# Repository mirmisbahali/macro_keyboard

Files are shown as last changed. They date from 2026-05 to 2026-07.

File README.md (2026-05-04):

# STM32 Macro Keyboard

A custom 6-key macro keyboard built from scratch custom written bare-metal STM32 firmware, hand-drawn schematics, and a PCB designed in KiCAD. No Arduino. No HAL. Just registers, datasheets, and stubbornness.

> **Status:** Hardware design in progress

---

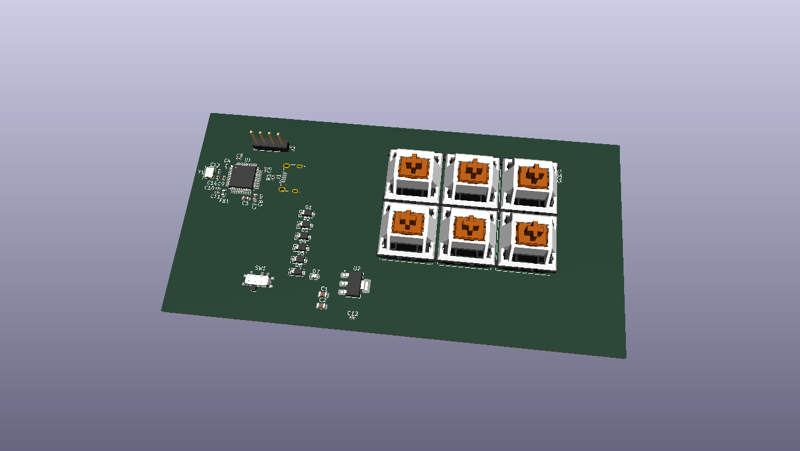
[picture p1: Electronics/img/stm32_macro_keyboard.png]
PCB


*PCB layout and routing in progress.*

Schematic

*Wiring is completed — schematic still needs to be made neat and tidy.*

<!-- Add photo of assembled board here -->
<!-- ![Board](docs/board.jpg) -->

---

## Why

I am learning to design STM32-based hardware - from choosing a microcontroller and designing the PCB, to writing drivers from scratch in register-level C.

## Hardware

| Item | Detail |
|---|---|
| MCU | STM32F072CBTx — Cortex-M0, 48 MHz, 128 KB flash, LQFP-48 |
| Key matrix | 6 switches with diode-per-key (1N4148W) |
| Power | 3.3 V core, ferrite bead on analog rail (VDDA), decoupling on all supply pins |
| Programming | USB DFU via BOOT0 SPDT switch — no debug probe needed |
| EDA tool | KiCAD 10.0 |

---

## Requirements

Requirements follow the systems engineering convention: **shall** = mandatory, **should** = desired.

### SYS — System
| ID | Requirement |
|---|---|
| SYS-01 | The device shall enumerate as a USB HID keyboard on any host OS without requiring driver installation. |
| SYS-02 | The device shall be powered entirely from the USB bus (5 V, ≤ 100 mA). |
| SYS-03 | The device shall support a minimum of 6 independently programmable macro keys. |
| SYS-04 | The device firmware shall be updatable via USB without a hardware debug probe. |
| SYS-05 | All firmware shall be written in register-level C with no vendor HAL or Arduino abstractions. |

### HW — Hardware
| ID | Requirement |
|---|---|
| HW-01 | The MCU core supply (VDD) shall be 3.3 V ± 5%. |
| HW-02 | Each VDD, VDDA, VBAT, and VSSIO2 supply pin shall have a dedicated decoupling capacitor placed within 2 mm of the pin. |
| HW-03 | VDDA shall be filtered from VDD using a ferrite bead to reduce digital noise on the analog supply. |
| HW-04 | Each key switch shall have a dedicated series diode to prevent ghosting in the key matrix. |
| HW-05 | The BOOT0 pin shall be switchable between VDD and GND via an SPDT switch to allow toggling between DFU programming mode and normal run mode. |
| HW-06 | The PCB shall pass KiCAD DRC with zero errors before submission for fabrication. |

### FW — Firmware
| ID | Requirement |
|---|---|
| FW-01 | The firmware shall configure the system clock to 48 MHz using the internal PLL before any peripheral initialisation. |
| FW-02 | The key scan loop shall debounce each key with a settling time of ≤ 5 ms. |
| FW-03 | The firmware shall report a key press to the USB host within 10 ms of a physical key actuation. |
| FW-04 | Macro key mappings shall be stored in non-volatile flash and survive a power cycle. |
| FW-05 | The firmware shall implement the USB HID boot-protocol keyboard descriptor to ensure compatibility with BIOS/UEFI environments. |

### VER — Verification
| ID | Requirement | Method |
|---|---|---|
| VER-01 | All supply rails measure within tolerance at board bring-up. | Test — multimeter |
| VER-02 | Device enumerates as HID keyboard on Windows, macOS, and Linux. | Test — plug in, check device manager |
| VER-03 | Every key registers a unique, correct HID keycode. | Test — key tester utility |
| VER-04 | Firmware can be flashed via DFU using only the BOOT0 switch and a USB cable. | Demonstration |
| VER-05 | Key mappings persist across power cycles. | Test — assign macro, power cycle, verify |
| VER-06 | PCB DRC passes with zero errors. | Analysis — KiCAD DRC report |

---

<details>
<summary><strong>Roadmap</strong></summary>

### Electronics
- [x] MCU symbol + footprint
- [x] Decoupling capacitors (VBAT, VDD, VDDA, VSSIO2)
- [x] BOOT0 SPDT switch for programming / run mode toggle
- [ ] USB data lines + ESD protection
- [ ] USB power input + 3.3 V regulator
- [ ] Key switch matrix (complete all 6 keys)
- [ ] PCB layout and routing
- [ ] DRC pass → Gerber export → fabrication

### Firmware
- [ ] Bare-metal project setup (linker script, startup file)
- [ ] System clock → 48 MHz via PLL
- [ ] GPIO driver — key matrix scan
- [ ] USB HID descriptor (boot-protocol keyboard)
- [ ] Key debounce
- [ ] Macro layer + flash storage for mappings

</details>

---

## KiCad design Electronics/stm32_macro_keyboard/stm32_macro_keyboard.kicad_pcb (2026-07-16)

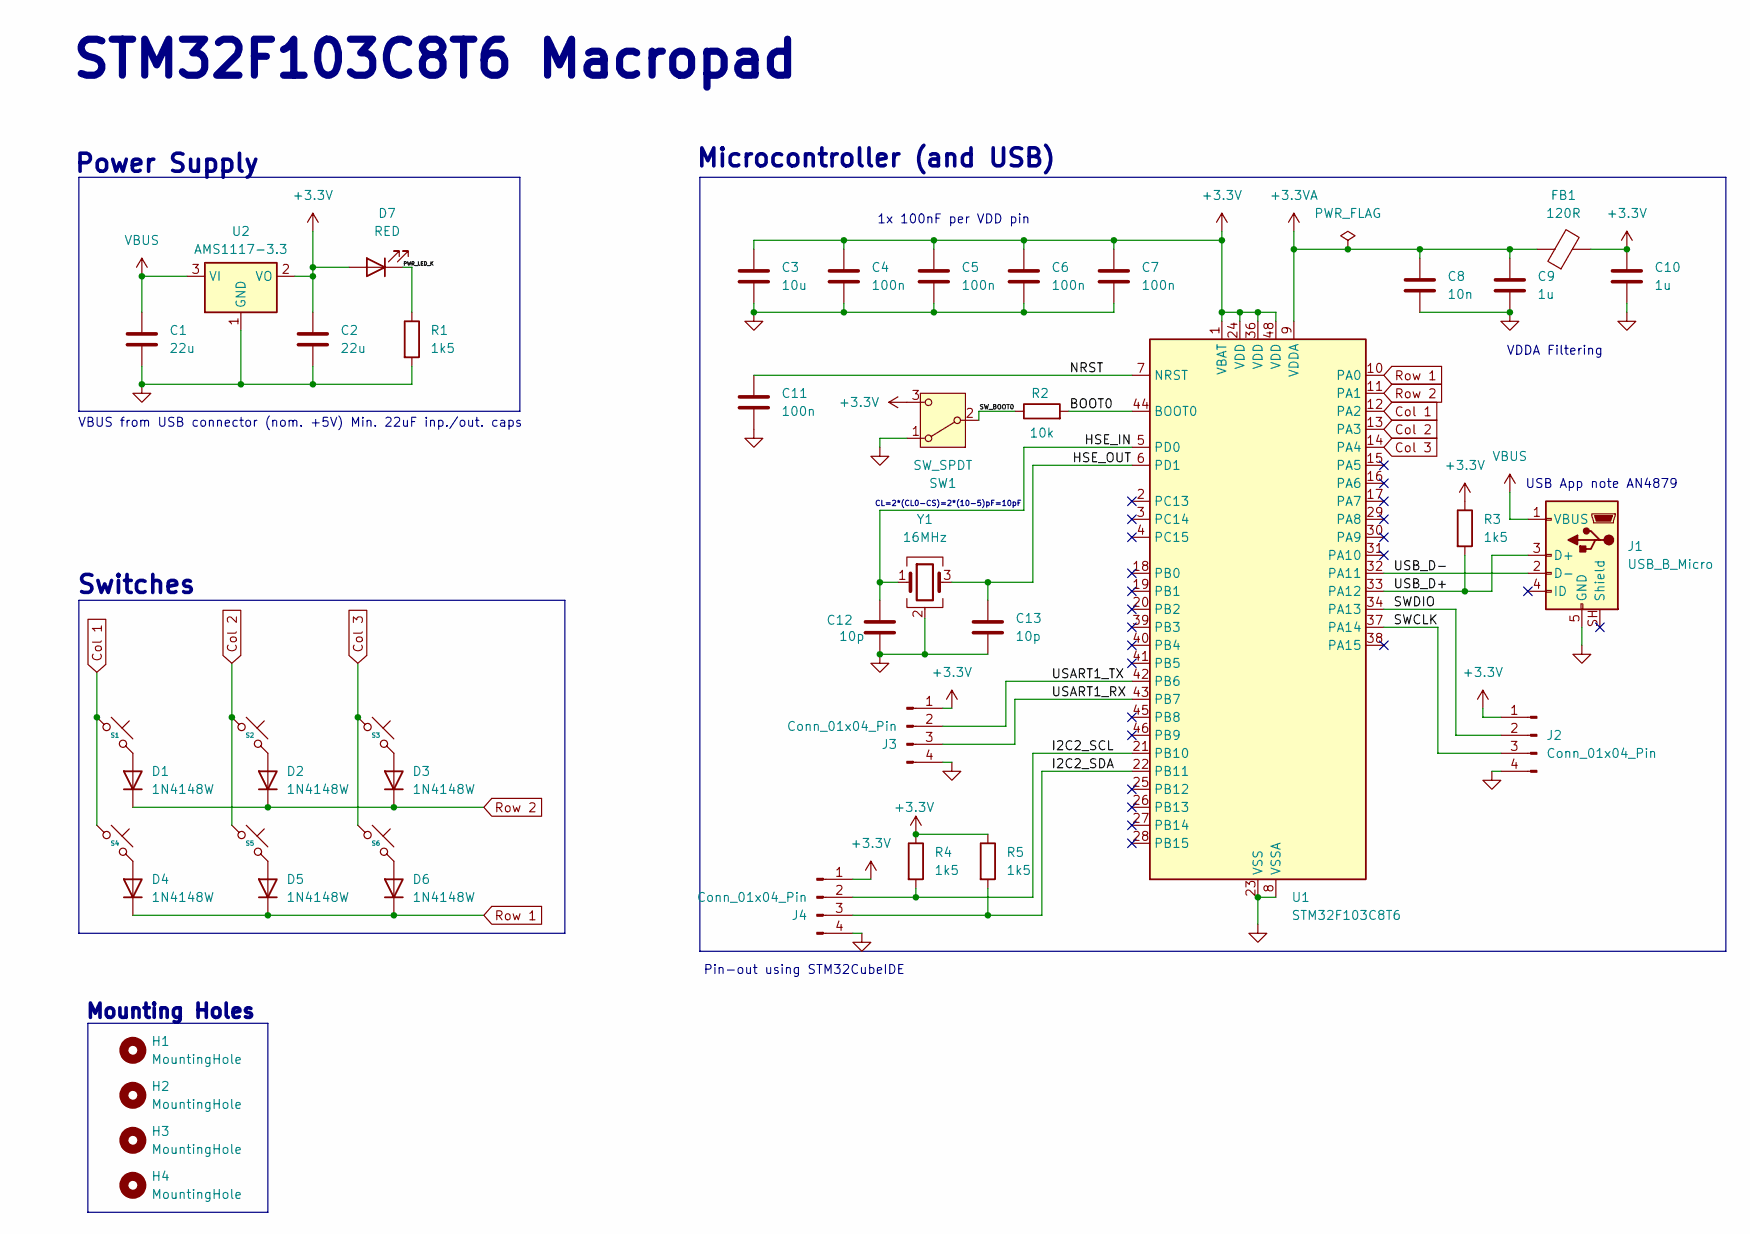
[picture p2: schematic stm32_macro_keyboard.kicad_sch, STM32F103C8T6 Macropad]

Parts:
C1, C2: 22u; C_0805_2012Metric
C3: 10u; C_0603_1608Metric
C4, C5, C6, C7, C11: 100n; C_0402_1005Metric
C8: 10n; C_0402_1005Metric
C9, C10: 1u; C_0402_1005Metric
C12, C13: 10p; C_0402_1005Metric
D1, D2, D3, D4, D5, D6: 1N4148W; D_SOD-123
D7: RED; LED_0603_1608Metric
FB1: 120R; L_0603_1608Metric
H1, H2, H3, H4: MountingHole; MountingHole_2.2mm_M2
J1: USB_B_Micro; USB_Micro-B_Wuerth_629105150521
J2, J3, J4: Conn_01x04_Pin; PinHeader_1x04_P2.54mm_Vertical
R1, R3, R4, R5: 1k5; R_0402_1005Metric
R2: 10k; R_0402_1005Metric
S1, S2, S3, S4, S5, S6: MX_PCB_2.50u
SW1: SW_SPDT; SW_SPDT_PCM12
U1: STM32F103C8T6; LQFP-48_7x7mm_P0.5mm
U2: AMS1117-3.3; SOT-223-3_TabPin2
Y1: 16MHz; Crystal_SMD_3225-4Pin_3.2x2.5mm

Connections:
+3.3V: C2.1, C3.1, C4.1, C5.1, C6.1, C7.1, C10.1, D7.2 (A), FB1.2, J2.1, J3.1, J4.1, R3.1, R4.1, R5.1, SW1.3 (C), U1.1 (VBAT), U1.24 (VDD), U1.36 (VDD), U1.48 (VDD), U2.2 (VO)
+3.3VA: C8.1, C9.1, FB1.1, U1.9 (VDDA)
/BOOT0: R2.2, U1.44 (BOOT0)
/HSE_IN: C12.1, U1.5 (PD0), Y1.1
/HSE_OUT: C13.1, U1.6 (PD1), Y1.3
/I2C2_SCL: J4.2, R4.2, U1.21 (PB10)
/I2C2_SDA: J4.3, R5.2, U1.22 (PB11)
/NRST: C11.1, U1.7 (NRST)
/PWR_LED_K: D7.1 (K), R1.1
/SWCLK: J2.3, U1.37 (PA14)
/SWDIO: J2.2, U1.34 (PA13)
/SW_BOOT0: R2.1, SW1.2 (B)
/USART1_RX: J3.3, U1.43 (PB7)
/USART1_TX: J3.2, U1.42 (PB6)
/USB_D+: J1.3 (D+), R3.2, U1.33 (PA12)
/USB_D-: J1.2 (D-), U1.32 (PA11)
Col 1: S1.1, S4.1, U1.12 (PA2)
Col 2: S2.1, S5.1, U1.13 (PA3)
Col 3: S3.1, S6.1, U1.14 (PA4)
GND: C1.2, C2.2, C3.2, C4.2, C5.2, C6.2, C7.2, C8.2, C9.2, C10.2, C11.2, C12.2, C13.2, J1.5 (GND), J2.4, J3.4, J4.4, R1.2, SW1.1 (A), U1.8 (VSSA), U1.23 (VSS), U1.35 (VSS), U1.47 (VSS), U2.1 (GND), Y1.2 (G), Y1.4 (G)
unnamed: D1.2 (A), S1.2
unnamed: D2.2 (A), S2.2
unnamed: D3.2 (A), S3.2
unnamed: D4.2 (A), S4.2
unnamed: D5.2 (A), S5.2
unnamed: D6.2 (A), S6.2
Row 1: D4.1 (K), D5.1 (K), D6.1 (K), U1.10 (PA0)
Row 2: D1.1 (K), D2.1 (K), D3.1 (K), U1.11 (PA1)
VBUS: C1.1, J1.1 (VBUS), U2.3 (VI)

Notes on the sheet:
Microcontroller (and USB)
Mounting Holes
VBUS from USB connector (nom. +5V) Min. 22uF inp./out. caps
STM32F103C8T6 Macropad
CL=2*(CL0-CS)=2*(10-5)pF=10pF
Switches
VDDA Filtering
1x 100nF per VDD pin
Pin-out using STM32CubeIDE
USB App note AN4879
Power Supply

Board: 2 copper layers, 44 parts (0 on the bottom side), 29 nets, no tracks yet.

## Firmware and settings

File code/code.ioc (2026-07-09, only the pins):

Mcu.UserName=STM32F103C8Tx
PA11.Signal=USB_DM
PA12.Signal=USB_DP
PA13.Signal=SYS_JTMS-SWDIO
PA14.Signal=SYS_JTCK-SWCLK
PB10.Signal=I2C2_SCL
PB11.Signal=I2C2_SDA
PB6.Signal=USART1_TX
PB7.Signal=USART1_RX
PD0-OSC_IN.Signal=RCC_OSC_IN
PD1-OSC_OUT.Signal=RCC_OSC_OUT

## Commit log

2026-04-18 Initial commit: KiCAD macropad project and .gitignore
    [stm32_macro_keyboard.kicad_pcb, stm32_macro_keyboard.kicad_sch]
2026-04-21 Add decoupling capacitors and BOOT0 SPDT switch for MCU power-up
    - Added decoupling capacitors on VBAT, VDD, VDDA, and VSSIO2 pins
    - Added SPDT switch on BOOT0 to toggle between programming and normal run mode
    - Completes all circuitry required to power up the STM32 microcontroller
    - Updated .gitignore to exclude KiCAD lock files and external_resources/
    [stm32_macro_keyboard.kicad_sch]
2026-04-21 Add README to track project progress
2026-04-23 Add net labels for USB, HSE oscillator, and SWD debug signals
    - USB_D- and USB_D+ labels connected to PA11/PA12 for full-speed USB
    - HSE_IN and HSE_OUT labels on PF0/PF1 for external crystal oscillator
    - SWDIO and SWCLK labels on PA13/PA14 for SWD debug interface
    [stm32_macro_keyboard.kicad_sch]
2026-04-23 Add 16 MHz HSE crystal oscillator circuit
    - Add Y1 (Crystal_GND24) 16 MHz crystal on PF0/PF1 (HSE_IN/HSE_OUT)
    - Add C11 and C12 (10pF) load capacitors for crystal oscillator
    - Add GND connection for crystal ground pins
    [stm32_macro_keyboard.kicad_sch]
2026-04-23 Add USB Micro B connector (J1) with power and data connections
    - Add J1 (USB_B_Micro) connector symbol
    - Connect D- and D+ to USB_D-/USB_D+ nets on PA11/PA12
    - Connect VBUS to VBUS power rail and GND pin to GND
    - Mark ID and Shield pins as no-connect
    [stm32_macro_keyboard.kicad_sch]
2026-04-25 Configure USB, SWD, and HSE pins in STM32CubeMX IOC file
    Assign PA11/PA12 for USB Device (DM/DP), PA13/PA14 for SWD debug
    (SWDIO/SWCLK), and PF0/PF1 for HSE external oscillator. Add USB and
    SYS IPs with SysTick. This wires the CubeMX model up to match the
    schematic-level connections already placed.
2026-04-25 Add SWD debug header (J2) and power symbols to schematic
    Add a 4-pin connector J2 for SWD debug access with +3.3V and GND power
    symbols. Route MCU SWD signals (SWDIO/SWCLK) to the new header via wires.
    [stm32_macro_keyboard.kicad_sch]
2026-04-25 Add 3.3V LDO power regulation circuit to schematic
    Adds the full USB 5V → 3.3V power supply sub-circuit required to power
    the STM32F072 MCU from the USB bus:
    - U2 (AMS1117-3.3, SOT-223): LDO regulator converting VBUS (5V) to
    +3.3V. Chosen for its wide availability, 1A output capability, and
    simple 3-pin SOT-223 footprint that is easy to hand-solder.
    - C13, C14 (22µF each): Bulk input and output bypass capacitors on the
    LDO, as recommended by the AMS1117 datasheet to ensure stability and
    suppress switching noise on the regulated rail.
    - D7 (LED) + R2 (1.5kΩ): Power-on indicator LED. R2 limits current to
    ~2mA from the 3.3V rail ((3.3V - 2V_f) / 1500Ω ≈ 0.9mA), keeping
    total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
    [stm32_macro_keyboard.kicad_sch]
2026-05-04 Add schematic images, begin PCB layout, and configure GPIO key matrix pins
    Electronics:
    - Added Electronics/img/ with a 3D PCB render (PNG) and schematic export (SVG)
    for use in the README and project documentation
    - Expanded kicad_pcb from a blank stub to a full board definition with layer
    stack, design rules, net classes, and initial component placement — PCB
    layout and routing now in active progress
    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
    [stm32_macro_keyboard.kicad_pcb, stm32_macro_keyboard.kicad_sch]
2026-07-09 Ignore STM32CubeIDE .metadata workspace folders
    These are machine-local IDE state, not project source.
2026-07-09 Finish schematic, tidy layout, and start STM32F103C8TX firmware
    Schematic editing is complete; footprint assignment and PCB layout
    are next. New CubeIDE project targets STM32F103C8TX replacing the
    old STM32F072 MCU (see archive/stm32f072cbtx-mcu for the prior
    STM32F0-based progress).
    [stm32_macro_keyboard.kicad_sch]
2026-07-15 assigned footprints
    [stm32_macro_keyboard.kicad_sch]
2026-07-16 Configure copper zone fill settings and add mounting holes to PCB layout
    [stm32_macro_keyboard.kicad_pcb, stm32_macro_keyboard.kicad_sch]
